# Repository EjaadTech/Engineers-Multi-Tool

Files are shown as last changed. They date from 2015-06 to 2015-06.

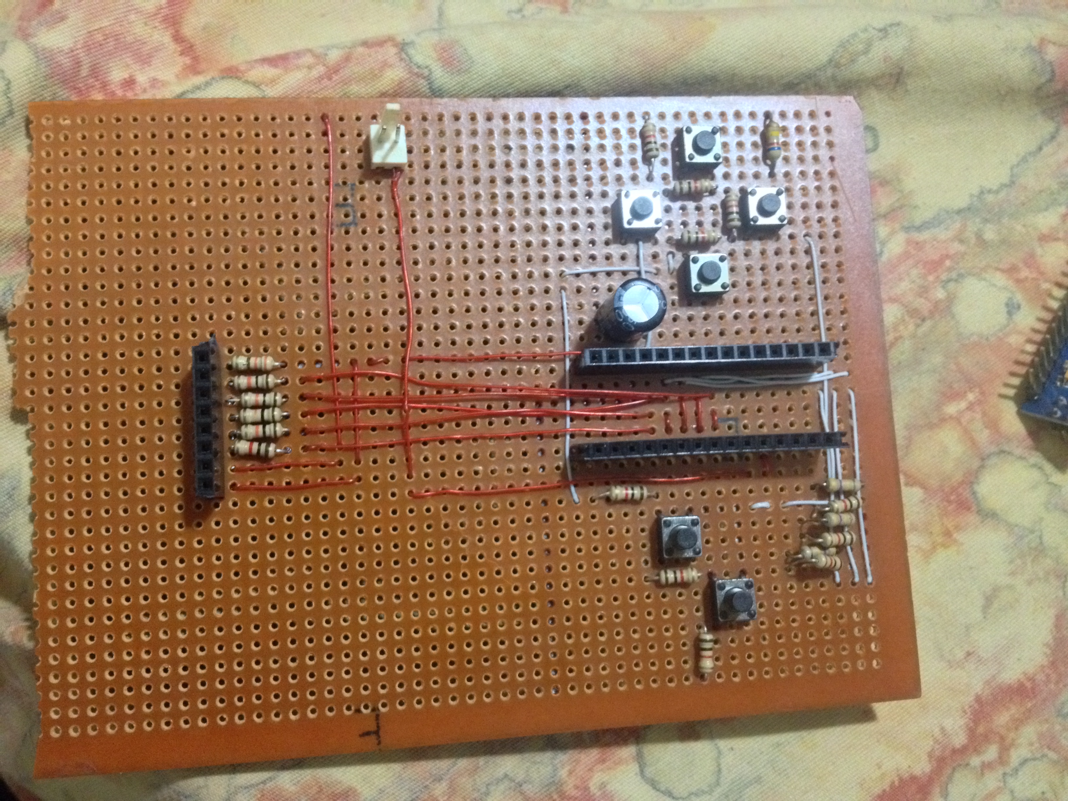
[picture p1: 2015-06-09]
hardware/IMG_5700.JPG

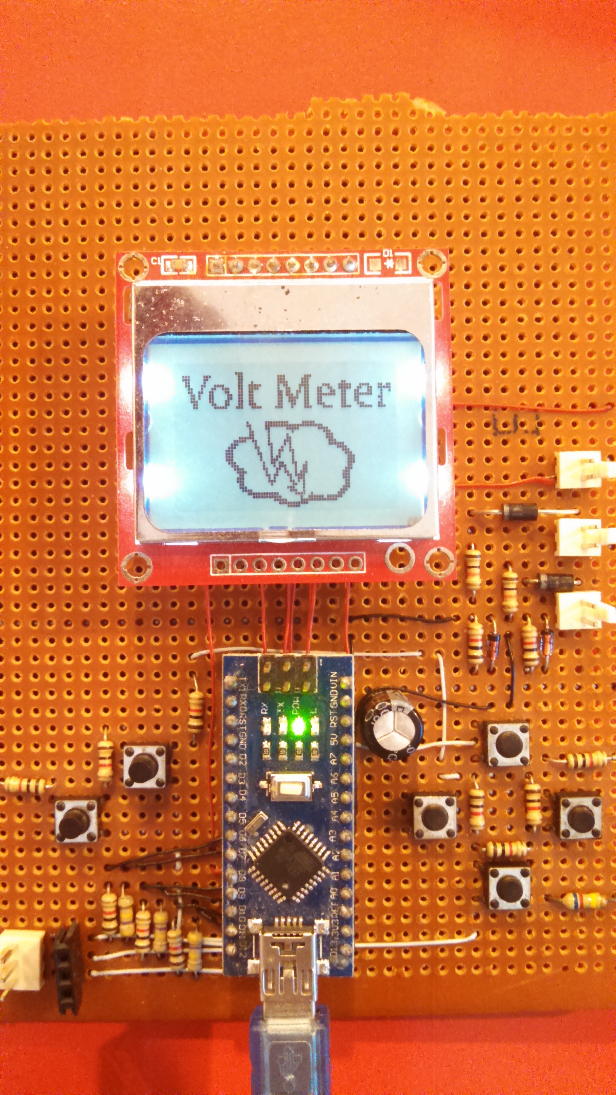
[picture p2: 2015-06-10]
hardware/IMG_20150610_111351_951.jpg

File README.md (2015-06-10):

# Engineers-Multi-Tool
yet another tool for electronics engineers to use on their workbench - planned to include Voltmeter, Ammeter, Component Tester, Serial Terminal, DAQ functionality, Waveform Generator.

A basic Arduino nano based portable device, having portable power, a basic display and circuitry to measure voltage, current, pulses, test components (Resistors, Capacitors, Transistors and more) and also be able to serve as a Serial Terminal and MORE.

## Planned Features
* Handheld formfactor - credit card/gameboy/mobile phone sized
* Arduino based
* Input Push Buttons - 6 to 10 buttons via 1 single ADC pin
* Nokia Graphics LCD - Mono, Mobile LCD for Display
* Voltage Input - 0 to 50V or possibly, -50 to 50V Voltmeter (2x)
* Current Input - 0 to 500mA or even possibly 1A Ammeter (FUSED)
* Serial Terminal - Show incoming Serial data on screen (adjustable/auto baudrate)
* Sqaure Wave Generator - basic clock generator, upto 1MHz with adjustable Duty Cycle
* Pulse Counter - Basic Pulse stats - Freq, Duty Cycle, etc
* Component Tester - a variant of the SemiConductor Tester
* Battery Powered - Chargeable via USB
* Serial Connection with PC - A basic data acquisition app on PC Side - Windows/Linux

### Suggest any other ideas that could be done..!

## TODO
* Upload Schematic
* Battery Charger integration
* Serial Terminal implementation
* Write more TODO List items...!

## WORK LOG
* Basic Circuit made on a protoboard
* LCD and Buttons Tested
* Simple Voltmeter 0.5 to 50V implemented
* Simple Pulse Generator Implemented with adjustable Freq/Duty
* Simple Menu interface implemented
* Integrate the Voltmeter, Pulse generator and Menu in one code
> DONE before 10th of June 2015

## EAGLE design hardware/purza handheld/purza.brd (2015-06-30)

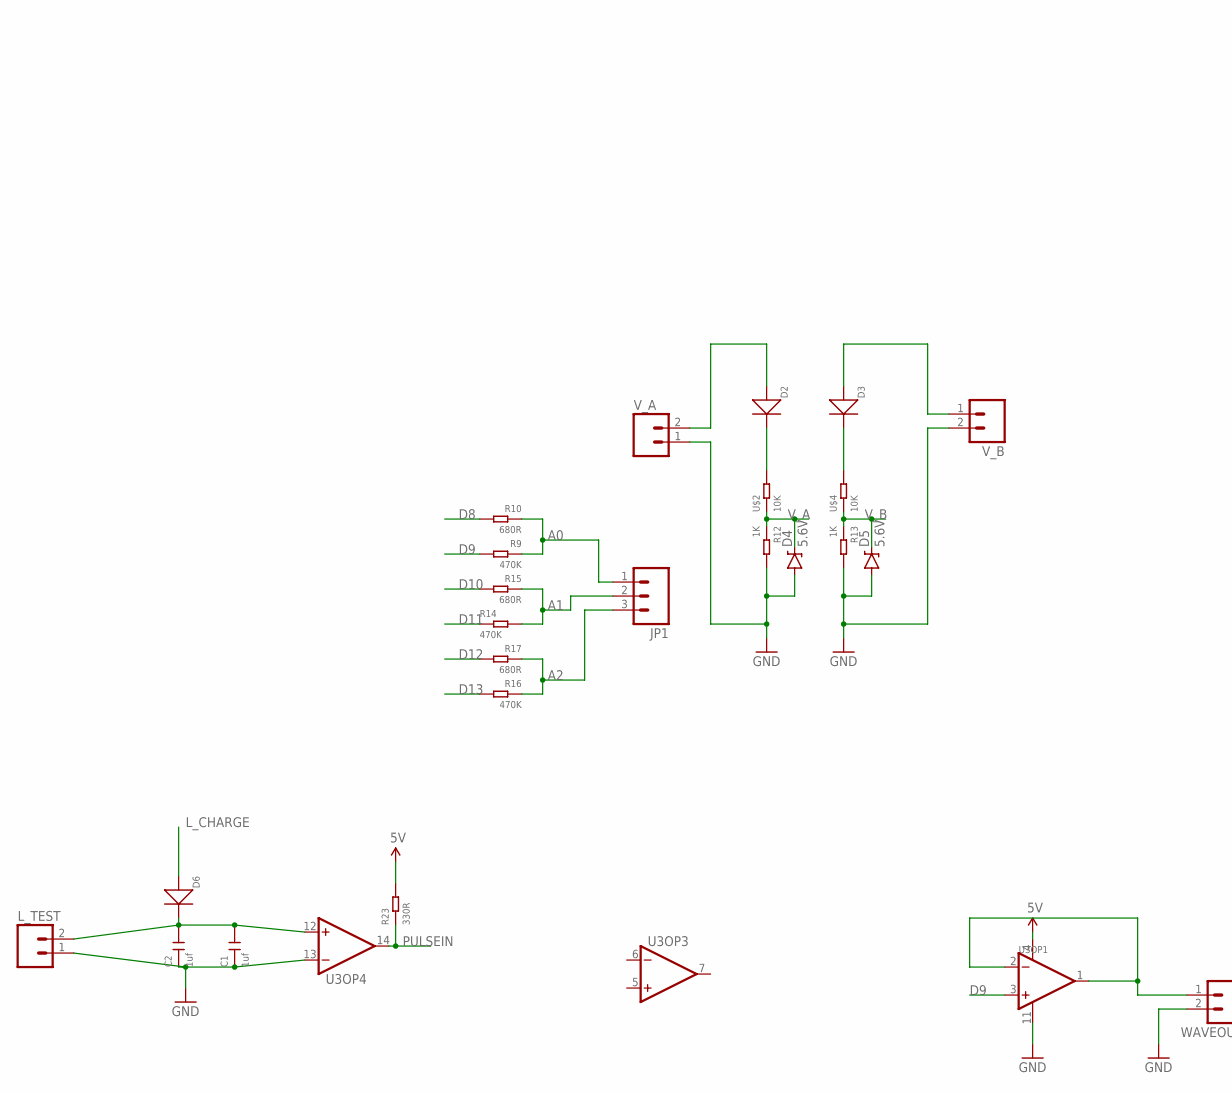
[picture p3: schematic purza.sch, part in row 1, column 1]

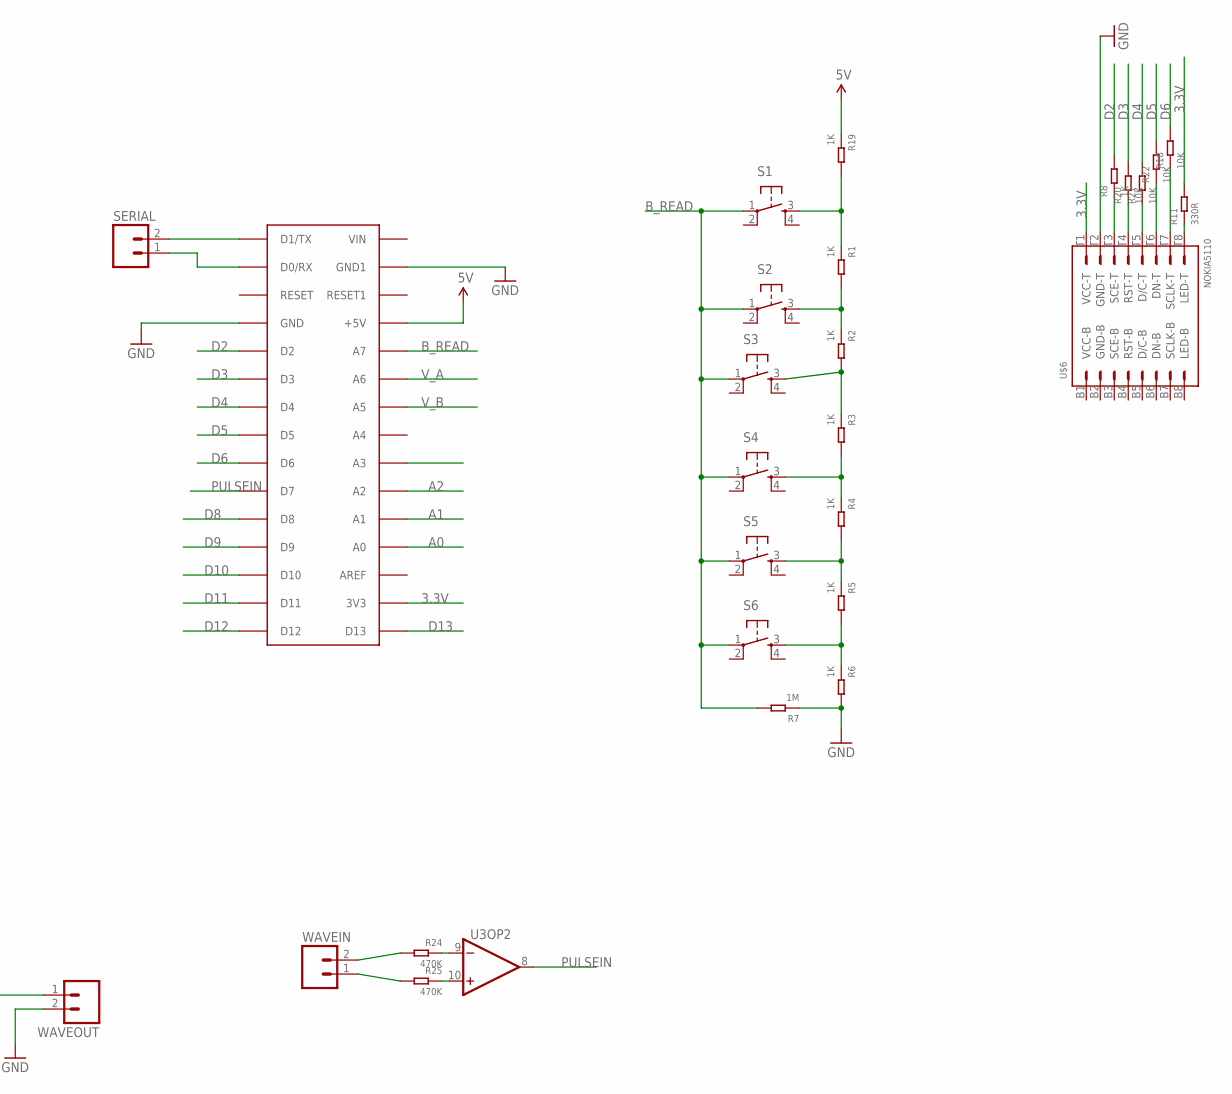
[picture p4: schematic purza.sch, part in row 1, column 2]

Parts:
C1, C2: 1uf; C0805
D2, D3, D6: DIODE'1206'; SOD-123
D4, D5: 5.6V; SOD-323
JP1: M03LOCK; 1X03_LOCK
L_TEST: M02LOCK; 1X02_LOCK
R1, R2, R3, R4, R5, R6, R8, R12, R13, R19: 1K; R0603
R7: 1M; R0603
R9, R14, R16, R24, R25: 470K; R0603
R10, R15, R17: 680R; R0603
R11, R23: 330R; R0603
R18, R20, R21, R22: 10K; R0603
S1, S2, S3, S4, S5, S6: TAC_SWITCHPTH; TACTILE-PTH
SERIAL: M02LOCK; 1X02_LOCK
U3: AMPLIFIER-LMV324IDR(SOIC14); SOIC14-1.27-9.3X4.3MM
U$1: ARDUINONANO; PDIP-32
U$2, U$4: 10K; R0805
U$6: NOKIA5110
V_A: M02LOCK; 1X02_LOCK
V_B: M02LOCK; 1X02_LOCK
WAVEIN: M02LOCK; 1X02_LOCK
WAVEOUT: M02LOCK; 1X02_LOCK

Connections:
3.3V: R11.2, U$1.3V3, U$6.T1 (VCC-T)
5V: R19.1, R23.2, U3.4 (V+), U$1.+5V
A0: JP1.1, R9.1, R10.1, U$1.A0
A1: JP1.2, R14.2, R15.1, U$1.A1
A2: JP1.3, R16.1, R17.1, U$1.A2
B_READ: R7.2, S1.1, S2.1, S3.1, S4.1, S5.1, S6.1, U$1.A7
D2: R8.2, U$1.D2
D3: R20.2, U$1.D3
D4: R21.2, U$1.D4
D5: R22.2, U$1.D5
D6: R18.2, U$1.D6
D8: R10.2, U$1.D8
D9: R9.2, U3.3 (IN+), U$1.D9
D10: R15.2, U$1.D10
D11: R14.1, U$1.D11
D12: R17.2, U$1.D12
D13: R16.2, U$1.D13
GND: C1.1, C2.1, D4.A, D5.A, L_TEST.1, R6.2, R7.1, R12.2, R13.2, U3.11 (V-), U3.13 (IN-), U$1.GND, U$1.GND1, U$6.T2 (GND-T), V_A.1, V_B.2, WAVEOUT.2
L_CHARGE: D6.+, U$1.A3
unnamed: D2.-, U$2.2
unnamed: D3.-, U$4.2
unnamed: R20.1, U$6.T4 (RST-T)
unnamed: R21.1, U$6.T5 (D/C-T)
unnamed: R22.1, U$6.T6 (DN-T)
unnamed: R18.1, U$6.T7 (SCLK-T)
unnamed: R11.1, U$6.T8 (LED-T)
unnamed: R8.1, U$6.T3 (SCE-T)
unnamed: D3.+, V_B.1
unnamed: R1.2, R2.1, S2.3
unnamed: R2.2, R3.1, S3.3
unnamed: R3.2, R4.1, S4.3
unnamed: R4.2, R5.1, S5.3
unnamed: SERIAL.2, U$1.D1/TX
unnamed: SERIAL.1, U$1.D0/RX
unnamed: R1.1, R19.2, S1.3
unnamed: D2.+, V_A.2
unnamed: U3.1 (OUT), U3.2 (IN-), WAVEOUT.1
unnamed: C1.2, C2.2, D6.-, L_TEST.2, U3.12 (IN+)
unnamed: R24.2, WAVEIN.2
unnamed: R25.2, WAVEIN.1
unnamed: R25.1, U3.10 (IN+)
unnamed: R24.1, U3.9 (IN-)
unnamed: R5.2, R6.1, S6.3
PULSEIN: R23.1, U3.8 (OUT), U3.14 (OUT), U$1.D7
V_A: D4.C, R12.1, U$1.A6, U$2.1
V_B: D5.C, R13.1, U$1.A5, U$4.1

Board: 2 copper layers, 50 parts (9 on the bottom side), 46 nets, no tracks yet.

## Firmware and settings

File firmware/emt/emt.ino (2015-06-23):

#include <avr/pgmspace.h>
#include <avr/wdt.h>
#include <avr/sleep.h>
#include <avr/power.h>
#include <EEPROM.h>

char foo;


//#define BUTTON_INST                              //Button Installed
//#define LCD_PRINT                                //Print on LCD
//Remember DEBUG_PRINT or ATSW
//#define ATSW                                   //ArduTester Software Client Enabled
#define DEBUG_PRINT                            //Print on Serial Port
//#define DET_COMP_ANALYSIS                        //Detailed Component Analysis (Soon)
//#define TIMEOUT_BL            600                //LCD Backlight Timeout
#define LONG_PRESS            26                 //Button Long Press
//#define USER_WAIT             3000               //Nexpage Timeout

//Check features



//UINT32_MAX
#define UINT32_MAX            ((uint32_t)-1)

//Test probes - Must be an ADC port :-)
#define ADC_PORT              PORTC              //ADC port data register 
#define ADC_DDR               DDRC               //ADC port data direction register 
#define ADC_PIN               PINC               //Port input pins register 
#define TP1                   0                  //Test pin 1 (=0) 
#define TP2                   1                  //Test pin 2 (=1) 
#define TP3                   2                  //Test pin 3 (=2) 
/*
Probe resistors:
The resistors must be connected to the lower 6 pins of the port in
following sequence:
- pin 0: Rl1 680R (test pin 1)
- pin 1: Rh1 470k (test pin 1)
- pin 2: Rl2 680R (test pin 2)
- pin 3: Rh2 470k (test pin 2)
- pin 4: Rl3 680R (test pin 3)
- pin 5: Rh3 470k (test pin 3)
*/
#define R_PORT                PORTB              //Port data register 
#define R_DDR                 DDRB               //Port data direction register

//Push button
#define TEST_BUTTON           A7                 //Test/start push button (low active)

//Button Delay
#define CYCLE_DELAY           3000

//ARDUESTER PARAMETERS

//Maximum number of measurements without any components found.
#define CYCLE_MAX             5
//ADC voltage reference based on Vcc (in mV). 
#define UREF_VCC              5001
/*
Offset for the internal bandgap voltage reference (in mV): -100 up to 100
- To compensate any difference between real value and measured value.
- The ADC has a resolution of about 4.88mV for V_ref = 5V (Vcc) and
1.07mV for V_ref = 1.1V (bandgap).
- Will be added to measured voltage of bandgap reference.
*/
#define UREF_OFFSET           0
/*
Exact values of probe resistors.
- Standard value for Rl is 680 Ohms.
- Standard value for Rh is 470k Ohms.
*/
//Rl in Ohms
#define R_LOW                 680
//Rh in Ohms
#define R_HIGH                470000
//Offset for systematic error of resistor measurement with Rh (470k) in Ohms.
#define RH_OFFSET             700 
/*
Resistance of probe leads (in 0.01 Ohms).
- Resistance of two probe leads in series.
- Assuming all probe leads got same/similar resistance.
*/
#define R_ZERO                20
/*
Capacitance of the wires between PCB and terminals (in pF).
Examples:
- 2pF for wires 10cm long
*/
#define CAP_WIRES             15
/*
Capacitance of the probe leads connected to the tester (in pF).
Examples:
capacity  length of probe leads
-------------------------------
3pF      about 10cm
9pF      about 30cm
15pF      about 50cm
*/
#define CAP_PROBELEADS        9
//Maximum voltage at which we consider a capacitor being discharged (in mV)
#define CAP_DISCHARGED        2
/*
Number of ADC samples to perform for each mesurement.
- Valid values are in the range of 1 - 255.
*/
#define ADC_SAMPLES           25
//Estimated internal resistance of port to GND (in 0.1 Ohms)
#define R_MCU_LOW             200                //Default: 209
//Estimated internal resistance of port to VCC (in 0.1 Ohms)
#define R_MCU_HIGH            220                //Default: 235
//Voltage offset of µCs analog comparator (in mV): -50 up to 50
#define COMPARATOR_OFFSET     15
//Capacitance of the probe tracks of the PCB and the µC (in pF)
#define CAP_PCB               42
//Total default capacitance (in pF): max. 255
#define C_ZERO                CAP_PCB + CAP_WIRES + CAP_PROBELEADS
//ATMEGA328, 16Mhz Related
#define ADC_CLOCK_DIV         (1 << ADPS2) | (1 << ADPS1) | (1 << ADPS0)
#define CPU_FREQ              F_CPU
#define OSC_STARTUP           16384

//Components ID's
#define COMP_NONE             0
#define COMP_ERROR            1
#define COMP_MENU             2
#define COMP_RESISTOR         10
#define COMP_CAPACITOR        11
#define COMP_INDUCTOR         12
#define COMP_DIODE            20
#define COMP_BJT              21
#define COMP_FET              22
#define COMP_IGBT             23
#define COMP_TRIAC            24
#define COMP_THYRISTOR        25

//Chars
#define LCD_CHAR_UNSET        0                  //Just a place holder 
#define LCD_CHAR_DIODE1       1                  //Diode icon '>|' 
#define LCD_CHAR_DIODE2       2                  //Diode icon '|<' 
#define LCD_CHAR_CAP          3                  //Capacitor icon '||' 
#define LCD_CHAR_FLAG         4                  //Flag Icon
#define LCD_CHAR_RESIS1       6                  //Resistor left icon '[' 
#define LCD_CHAR_RESIS2       7                  //Resistor right icon ']'
#ifdef DEBUG_PRINT
#define LCD_CHAR_OMEGA      79              
#define LCD_CHAR_MICRO      '\u00B5'           //Code for Arduino Serial Monitor
#else
#define LCD_CHAR_OMEGA      244                //Default: 244 
#define LCD_CHAR_MICRO      228
#endif

//Error type IDs
#define TYPE_DISCHARGE        1                  //Discharge error

//FET type bit masks (also used for IGBTs)
#define TYPE_N_CHANNEL        0b00000001         //n channel 
#define TYPE_P_CHANNEL        0b00000010         //p channel 
#define TYPE_ENHANCEMENT      0b00000100         //Enhancement mode 
#define TYPE_DEPLETION        0b00001000         //Depletion mode 
#define TYPE_MOSFET           0b00010000         //MOSFET 
#define TYPE_JFET             0b00100000         //JFET 
#define TYPE_IGBT             0b01000000         //IGBT (no FET) 

//Mode bitmask
#define MODE_LOW_CURRENT      0b00000001         //Low test current 
#define MODE_HIGH_CURRENT     0b00000010         //High test current 
#define MODE_DELAYED_START    0b00000100         //Delayed start

//BJT (bipolar junction transistor) type IDs 
#define TYPE_NPN              1                  //NPN
#define TYPE_PNP              2                  //PNP

//Tester operation modes
#define MODE_CONTINOUS        0                  //Continous
#define MODE_AUTOHOLD         1                  //Auto hold 

//Multiplicator tables
#define TABLE_SMALL_CAP       1
#define TABLE_LARGE_CAP       2
#define TABLE_INDUCTOR        3

//Bit flags for PullProbe()
#define FLAG_PULLDOWN         0b00000000
#define FLAG_PULLUP           0b00000001
#define FLAG_1MS              0b00001000
#define FLAG_10MS             0b00010000

//Tester modes, offsets and values
typedef struct
{
	byte                        TesterMode;        //Tester operation mode
	byte                        SleepMode;         //MCU sleep mode 
	byte                        Samples;           //Number of ADC samples 
	byte                        AutoScale;         //Flag to disable/enable ADC auto scaling 
	byte                        RefFlag;           //Internal control flag for ADC 
	unsigned int                U_Bandgap;         //Voltage of internal bandgap reference (mV) 
	unsigned int                RiL;               //Internal pin resistance of µC in low mode (0.1 Ohms) 
	unsigned int                RiH;               //Internal pin resistance of µC in high mode (0.1 Ohms) 
	unsigned int                RZero;             //Resistance of probe leads (2 in series) (0.01 Ohms) 
	byte                        CapZero;           //Capacity zero offset (input + leads) (pF) 
	signed char                 RefOffset;         //Voltage offset of bandgap reference (mV) 
	signed char                 CompOffset;        //Voltage offset of analog comparator (mV) 
} Config_Type;

//Probes
typedef struct
{
	//Probe pins
	byte                        Pin_1;             //Probe-1
	byte                        Pin_2;             //Probe-2
	byte                        Pin_3;             //Probe-3 
	//Bit masks for switching probes and test resistors
	byte                        Rl_1;              //Rl mask for probe-1 
	byte                        Rh_1;              //Rh mask for probe-1 
	byte                        Rl_2;              //Rl mask for probe-2 
	byte                        Rh_2;              //Rh mask for probe-2 
	byte                        Rl_3;              //Rl mask for probe-3 
	byte                        Rh_3;              //Rh mask for probe-3 
	byte                        ADC_1;             //ADC mask for probe-1 
	byte                        ADC_2;             //ADC mask for probe-2 
} Probe_Type;

//Checking/probing
typedef struct
{
	byte                        Done;              //Flag for transistor detection done 
	byte                        Found;             //Component type which was found 
	byte                        Type;              //Component specific subtype 
	byte                        Resistors;         //Number of resistors found 
	byte                        Diodes;            //Number of diodes found 
	byte                        Probe;             //Error: probe pin 
	unsigned int                U;                 //Error: voltage left in mV 
} Check_Type;

//Resistor
typedef struct
{
	byte                        A;                 //Probe pin #1 
	byte                        B;                 //Probe pin #2 
	byte                        Scale;             //Exponent of factor (value * 10^x) 
	unsigned long               Value;             //Resistance 
} Resistor_Type;

//Capacitor
typedef struct
{
	byte                        A;                 //Probe pin #1 
	byte                        B;                 //Probe pin #2 
	signed char                 Scale;             //Exponent of factor (value * 10^x) 
	unsigned long               Value;             //Capacitance incl. zero offset 
	unsigned long               Raw;               //Capacitance excl. zero offset 
} Capacitor_Type;

//Inductor
typedef struct
{
	signed char                 Scale;             //Exponent of factor (value * 10^x) 
	unsigned long               Value;             //Inductance 
} Inductor_Type;

//Diode
typedef struct
{
	byte                        A;                 //Probe pin connected to anode 
	byte                        C;                 //Probe pin connected to cathode 
	unsigned int                V_f;               //Forward voltage in mV (high current) 
	unsigned int                V_f2;              //Forward voltage in mV (low current) 
} Diode_Type;

//Bipolar junction transistor
typedef struct
{
	byte                        B;                 //Probe pin connected to base 
	byte                        C;                 //Probe pin connected to collector 
	byte                        E;                 //Probe pin connected to emitter 
	unsigned long               hFE;               //Current amplification factor 
	//U_BE voltage
	unsigned int                I_CE0;             //Leakage current (in µA) 
} BJT_Type;

//FET
typedef struct
{
	byte                        G;                 //Test pin connected to gate 
	byte                        D;                 //Test pin connected to drain 
	byte                        S;                 //Test pin connected to source 
	unsigned int                V_th;              //Threshold voltage of gate in mV 
} FET_Type;

//Error (failed discharge) - Deprecated
typedef struct
{

} Error_Type;

//Output buffers 
char                          OutBuffer[12];
char                          PRGBuffer[32];

//Configuration
Config_Type                   Config;            //Tester modes, offsets and values 

//Probing
Probe_Type                    Probes;            //Test probes 
Check_Type                    Check;             //Checking/testing 

//Components
Resistor_Type                 Resistors[3];      //Resistors (3 combinations) 
Capacitor_Type                Caps[3];           //Capacitors (3 combinations) 
Diode_Type                    Diodes[6];         //Diodes (3 combinations in 2 directions) 
BJT_Type                      BJT;               //Bipolar junction transistor 
FET_Type                      FET;               //FET 
Inductor_Type                 Inductor;          //Inductor

//Store String to Flash Functions :-)
class __FlashStringHelper;
#define X(str) (strcpy_P(PRGBuffer, PSTR(str)), PRGBuffer)
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
void loop()
{
	ButtonRead = analogRead(A7);
	delay(20);
	
	Menu();
	
}

void SerialDisplay()
{
	byte testloop=0;
	display.setTextSize(1);
	while (ButtonRead < 800)
	{
		delay(200);
		display.clearDisplay();
		ButtonRead = analogRead(A7);
		
		display.print("Baud Rate\n");
		display.print(BaudRate[BaudCount]);
		display.display();
		
		if (ButtonRead>400 && ButtonRead < 500)
		{
			BaudCount++;
			if (BaudCount >= 10)
				BaudCount = 0;
			delay(200);
			Serial.begin(BaudRate[BaudCount]);
		}
		else if (ButtonRead>100 && ButtonRead < 200)
		{
			BaudCount--;
			if (BaudCount >10)
				BaudCount = 9;
			delay(200);
			Serial.begin(BaudRate[BaudCount]);
		}
		
		if (ButtonRead > 700 && ButtonRead < 800)
		{
			display.clearDisplay();
			display.print("Serial Begin");
			display.display();
			delay(1000);
			display.clearDisplay();
			display.display();
			ReadSerial = "";
			lineCount = 0;
			charCount = 0;
			while (ButtonRead <800 )
			{
				ButtonRead = analogRead(A7);
				if (ButtonRead > 700 && ButtonRead < 800)
					break;
				while (Serial.available()) {
					char inChar = (char)Serial.read();
					ReadSerial += inChar;
					if (inChar == '\n'){
						lineCount++;
						charCount = 0;
					}
					else
						charCount++;
					if (charCount >= 12){
						ReadSerial += '\n';
						lineCount++;
						charCount = 0;
					}
					if (lineCount > 6){
						unsigned char firstLine = ReadSerial.indexOf('\n');
						

						for (int a = 0; a < ReadSerial.length() - 1 - firstLine; a++){
							ReadSerial[a] = ReadSerial[a + firstLine + 1];
						}
					
						for (int a = ReadSerial.length() - 1 - firstLine; a < ReadSerial.length() - 1; a++){
							ReadSerial.remove(a);
						}
						
						lineCount--;
					}
					testloop = 1;
				}
				if (testloop == 1)
				{

					display.clearDisplay();
					display.print(ReadSerial);
					display.display();
					testloop = 0;
				}
				
				
				
				}
				
			ButtonRead = analogRead(A7);
			
		}
		}
	}

void Menu()
{
	if (ButtonRead > 100 && ButtonRead < 200)
	{
		MenuUp();
		count++;
		if (count == 4)
			count = 0;
	}
	else if (ButtonRead > 400 && ButtonRead < 500)
	{
		count--;
		if (count < 0)
			count = 3;
		MenuDown();

	}



	if (count == 1 && ButtonRead > 700 && ButtonRead < 800)
	{
		VoltageRead();
		display.clearDisplay();
		display.setTextSize(1);
		//display.drawBitmap(0, 0, menu[count - 1], 84, 48, 1);
		display.print(menu[count-1]);
		display.display();
	}
	else if (count == 2 && ButtonRead > 700 && ButtonRead < 800)
	{
		FrequencySet();
		display.clearDisplay();
		display.setTextSize(1);
		display.print(menu[count-1]);
		//display.drawBitmap(0, 0, menu[count - 1], 84, 48, 1);
		display.display();

	}
	else if (count == 0 && ButtonRead > 700 && ButtonRead < 800)
	{
		SerialDisplay();
		display.clearDisplay();
		display.print(menu[3]);
		//display.drawBitmap(0, 0, menu[3], 84, 48, 1);
		
		display.display();
	}
	else if (count == 3 && ButtonRead > 700 && ButtonRead < 800)
	{
		while (ButtonRead < 800)
		{
			
			ButtonRead = analogRead(A7);
			display.clearDisplay();
			display.print("Press Start ToBegin....!");
			display.display();
			delay(100);
			if (ButtonRead > 700 && ButtonRead < 800)
			SemiProbing();
			
		}
		display.clearDisplay();
		display.print(menu[count-1]);
		//display.drawBitmap(0, 0, menu[count-1], 84, 48, 1);
		
		display.display();
		delay(10);
	}
}

void MenuUp()
{
	for (int i = 0; i <=48; i += 4)
	{ 
		display.clearDisplay();
		display.setCursor(0, i);
		display.print(menu[count == 0 ? 3 : (count - 1)]);
		display.setCursor(0, i-48);
		display.print(menu[count]);
		//display.drawBitmap(0, i, menu[count==0 ? 3 : (count-1) ], 84, 48, 1);
		//display.drawBitmap(0, i-48, menu[count], 84, 48, 1);
		display.display();
		delay(10);

	}
	
}

void MenuDown()
{
	
	for (int i = 48; i >= 0; i-=4)
	{
		display.clearDisplay();
		display.setCursor(0, i);
		display.print(menu[count == 0 ? 3 : (count - 1)]);
		display.setCursor(0, i-48);
		display.print(menu[count]);
		//display.drawBitmap(0, i, menu[count == 0 ? 3 : (count - 1)], 84, 48, 1);
		//display.drawBitmap(0, i - 48, menu[count], 84, 48, 1);
		display.display();
	}
}

void VoltageRead()
{
	delay(50);
	display.setTextSize(3);
	while (ButtonRead < 800)
	{
		ButtonRead = analogRead(A7);
		
		VoltageA = analogRead(A6)*5.0 / 1023.0;
		VoltageA = VoltageA * 11;
		VoltageB = analogRead(A5)*5.0 / 1023.0;
		VoltageB = VoltageB * 11;
		display.clearDisplay();
		if (VoltageA > 0)
		{
			VoltageA += 0.5;
		}
		if (VoltageB > 0)
		{
			VoltageB += 0.5;
		}
		if (VoltageA >= 10)
			display.print(VoltageA, 1);
		else
			display.print(VoltageA);
		display.println(VoltageB);
		display.display();
		display.setRotation(2);
		display.fillRoundRect(1, -2, 4, map(VoltageB,0,56,0,48), 1, 1);
		display.fillRoundRect(7, -2, 4, map(VoltageA, 0, 56, 0, 48), 1, 1);
		display.setRotation(0);
		display.display();
		delay(70);
	}
}
void calculation()
{
	Test = 8000000;

	for (int i = 4; i >= 0; i--)
	{

		RegValue[i] = (Crystal / (prescale[i] * InputFrequency)) - 1;


		if (InputFrequency<500)
			Frequency[i] = Crystal / (prescale[i] * RegValue[i]);
		else
			Frequency[i] = Crystal / (prescale[i] * ((int)RegValue[i] + 1));
		RegValue[i] = (int)RegValue[i];
		temp[i] = Frequency[i] - InputFrequency;
		if (temp[i]<0)
			temp[i] = InputFrequency - Frequency[i];


		if (temp[i] == 0)
		{
			FinalReg = i;
			break;
		}
		if (Test >= temp[i])
		{
			Test = temp[i];
			FinalReg = i;

		}

	}



	regsetting();
}

void regsetting()
{
	if (prescale[FinalReg] == 1)
	{
		TCCR1B = (1 << CS10) | (1 << WGM13) | (1 << WGM12);
	}
	else if (prescale[FinalReg] == 8)
	{
		TCCR1B = (1 << CS11) | (1 << WGM13) | (1 << WGM12);
	}
	else if (prescale[FinalReg] == 64)
	{
		TCCR1B = (1 << CS11) | (1 << CS10) | (1 << WGM13) | (1 << WGM12);
	}
	else if (prescale[FinalReg] == 256)
	{
		TCCR1B = (1 << CS12) | (1 << WGM13) | (1 << WGM12);
	}
	else if (prescale[FinalReg] == 1024)
	{
		TCCR1B = (1 << CS12) | (1 << CS10) | (1 << WGM13) | (1 << WGM12);
	}
	else
		TCCR1B = 0;
	TCCR1A = 0x82;
	ICR1 = RegValue[FinalReg];
	OCR1A = RegValue[FinalReg] * duty / 100;




}
void FrequencySet()
{
	pinMode(9, OUTPUT);
	while (ButtonRead < 800)
	{
		display.clearDisplay();
		display.setTextSize(1);
		display.setTextColor(BLACK);
		display.setCursor(0, 0);
		ButtonRead = analogRead(A7);

		if (ButtonRead > 700 && ButtonRead < 800)
		{
			ButtonRead = analogRead(A7);
			delay(400);
			while (ButtonRead < 800)
			{

				SetFreq();
				if (ButtonRead > 700 && ButtonRead <800)
				{
					delay(400);
					break;
				}
				if (ButtonRead>400 && ButtonRead < 500)
				{
					while (ButtonRead < 800)
					{
						SetDuty();
						if ((ButtonRead>100 && ButtonRead < 200) || (ButtonRead > 700 && ButtonRead < 800))
							break;

					}
				}


			}



		}
		else
		{

			display.print("FREQ ");
			display.println(Frequency[FinalReg]);
			display.print("DUTY ");
			display.print(duty);
			display.println("%");
			DutyBar = map(duty, 0, 100, 0, 83);
			display.drawLine(DutyBar - 1, 47, 83, 47, BLACK);
			display.fillRect(-1, 31, DutyBar - 2, 18, BLACK);
			display.drawRect(-1, 29, DutyBar, 20, BLACK);
			display.display();
		}

	}
}

void SetFreq()
{
	display.clearDisplay();
	display.setTextSize(2);
	display.setTextColor(BLACK);
	display.setCursor(0, 0);
	ButtonRead = analogRead(A7);
	display.clearDisplay();
	display.println("  FREQ");
	display.print(Frequency[FinalReg],0);


	display.display();

	if (ButtonRead > 500 && ButtonRead < 600)
	{
		if (InputFrequency <300 && InputFrequency>=0)
		{
			InputFrequency --;

			
		}
		else if (InputFrequency<1000)
		{
			InputFrequency-=100;

		}
		else
		{
			InputFrequency -= 1000;
		}

		calculation();
		delay(20);

	}
	else if (ButtonRead > 200 && ButtonRead < 300)
	{
		if (InputFrequency <= 300)
		{
			InputFrequency++;

		}
		else if (InputFrequency <= 1000)
		{
			InputFrequency += 100;
		}
		else 
		{
			InputFrequency += 1000;
		}

		calculation();
		delay(50);
	}
}
void SetDuty()
{
	ButtonRead = analogRead(A7);
	display.clearDisplay();
	display.setTextSize(2);
	display.setTextColor(BLACK);
	display.println(" DUTY");
	display.print(duty);
	display.println("%");
	DutyBar = map(duty, 0, 100, 0, 83);
	display.drawLine(DutyBar - 1, 47, 83, 47, BLACK);
	display.fillRect(-1, 33, DutyBar - 2, 18, BLACK);
	display.drawRect(-1, 31, DutyBar, 19, BLACK);
	display.display();

	if (ButtonRead > 200 && ButtonRead < 300)
	{
		if (duty <= 100)
		{
			duty = duty + 1;
			calculation();
			delay(100);
		}

	}
	else if (ButtonRead>500 && ButtonRead < 600)
	{
		if (duty >= 0)
			duty = duty - 1;
		calculation();
		delay(100);
	}
}
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

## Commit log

2015-06-09 Initial Commit - Menu Testing, Voltmeter+WaveGen. done already
    Not so initial already tested voltmeter & square wave generator - current commit only shows the menu currently in testing
2015-06-09 added hardware images - first prototype
2015-06-10 Serial Integerated with UI but Some Display Bugs
    [emt.ino]
2015-06-11 Serial Display and Performance Bug Pix
    [emt.ino]
2015-06-22 component tester include with main file but size issue
    [emt.ino]
2015-06-22 Revert "Change bmp to simple text but still running out of memory"
    This reverts commit bb7e83f6d62d605439a3e98b5dcddaa700df4024.
    [emt.ino]
2015-06-23 Run Out Of Memory Switch To Text format
2015-06-30 PCB Schematic
    [purza.brd, purza.sch]

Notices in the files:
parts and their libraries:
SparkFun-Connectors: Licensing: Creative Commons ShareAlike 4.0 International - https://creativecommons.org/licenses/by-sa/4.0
